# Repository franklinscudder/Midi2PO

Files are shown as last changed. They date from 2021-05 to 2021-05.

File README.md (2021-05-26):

# Midi2PO
 A device that takes MIDI clock in and outputs 1v pulses at PPQN intervals compatible with a range of devices including Korg volcas and Teenage Engineering pocket operators.

## V1
An initial design outputting a 2PPQN signal for PO/Volcas.

## V2 (LC)
An untested lower cost design using a ATTiny uController.

## V3 (Switchable)
An iteration including a second LED indicator as well as a DIP switch bank to allow a range of PPQN values to be output.
Available PPQNS: 0.25, 0.5, 1, 2, 4, 6, 12, 24.

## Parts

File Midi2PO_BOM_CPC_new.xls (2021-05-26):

Line Number | Order Code | Manufacturer Name | Manufacturer Part Number | Description | Requested Qty | Quoted Qty | Unit Price | Line Price | Availability | Lead Time
1 | SC15554 | MULTICOMP PRO | 1N4148 (DO-35) | 1N4148 (DO-35)-Small Signal Diode, Single, 100 V, 150 mA, 1 V, 4 ns, 2 A | 5 | 5 | £0.03 | £0.15 | 1761 | 1,761 in stock ready for despatch (UK stock)
2 | SC15646 | SEEED STUDIO | 102010328 | 102010328-Seeeduino XIAO Arduino Controller, SAMD21 Cortex M0+ | 1 | 1 | £5.98 | £5.98 | 63 | 63 in stock ready for despatch (UK stock)
3 | SC17276 | ON SEMICONDUCTOR | 6N138M | 6N138M-OPTOCOUPLER, DARLINGTON, 5KV, DIP-8 | 1 | 1 | £0.89 | £0.89 | 16 | 16 in stock ready for despatch (UK stock)
4 | CN21849 | MULTICOMP | SPC21344 | SPC21344-3.5mm Jack Socket, Stereo 3 Pole Switched, PCB | 1 | 1 | £0.77 | £0.77 | 61 | 61 in stock ready for despatch (UK stock)
5 | SC15414 | MULTICOMP PRO | MCL053GD | MCL053GD-LED, Green, 5mm, 2.1V | 10 | 10 | £0.05 | £0.50 | 1454 | 1,454 in stock ready for despatch (UK stock)
6 | AV19824 | PRO SIGNAL | PSG03463 | PSG03463-5 Pin PCB Mount DIN Socket with Silver Plated Contacts | 1 | 1 | £0.78 | £0.78 | 355 | 355 in stock ready for despatch (UK stock)
7 | SC16304 | TEXAS INSTRUMENTS | TL071CP | TL071CP-IC, OP AMP, JFET LOW NOISE, DIP8 | 1 | 1 | £0.43 | £0.43 | Out of Stock
8 | SW05533 | MULTICOMP PRO | MCNDA-03V | MCNDA-03V-DIP Switch, 3-Pole, SPST-NO, Slide Actuation, 24VDC, Right Angle | 1 | 1 | £0.50 | £0.50 | 11 | 11 in stock ready for despatch (UK stock)
9 | RE03791 | MULTICOMP PRO | MCF 0.25W 100R | MCF 0.25W 100R-Resistor, 0.25W 5% 100R, 100 Pack | 1 | 1 | £0.55 | £0.55 | 272 | 272 in stock ready for despatch (UK stock)
10 | RE03806 | MULTICOMP PRO | MCF 0.25W 1K8 | MCF 0.25W 1K8-Resistor, 0.25W 5% 1K8, 100 Pack | 1 | 1 | £0.55 | £0.55 | 17 | 17 in stock ready for despatch (UK stock)
11 | RE03798 | MULTICOMP PRO | MCF 0.25W 390R | MCF 0.25W 390R-Resistor, 0.25W 5% 390R, 100 Pack | 1 | 1 | £0.55 | £0.55 | 12 | 12 in stock ready for despatch (UK stock)

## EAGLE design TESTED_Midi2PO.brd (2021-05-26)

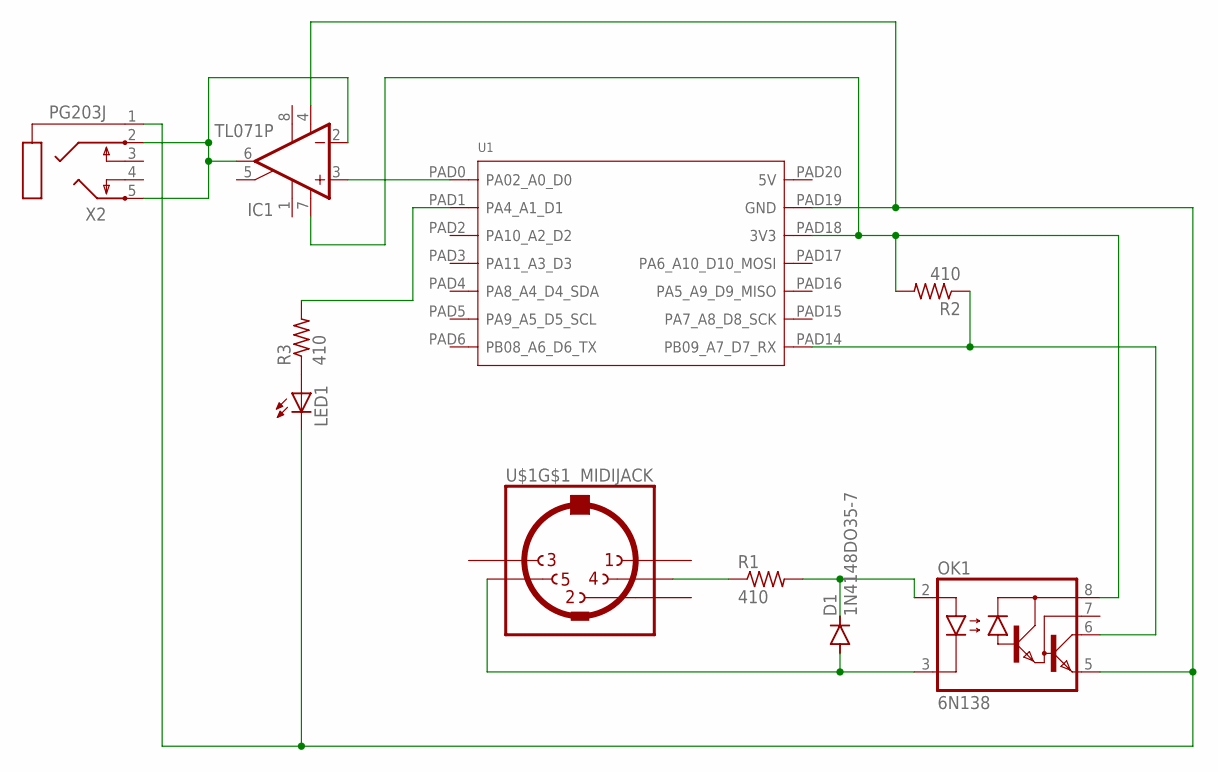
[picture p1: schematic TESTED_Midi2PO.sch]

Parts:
D1: 1N4148DO35-7; DO35-7
IC1: TL071P; DIL08
LED1: LED5MM
OK1: 6N138; DIL08
R1, R2, R3: 410; 0207/9
U1: MOUDLE-SEEEDUINO-XIAO; MOUDLE14P-2.54-21X17.8MM
U$1: MIDIJACK; CP-2350
X2: PG203J

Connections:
unnamed: D1.C, OK1.2 (A), R1.2
unnamed: R1.1, U$1.4
unnamed: D1.A, OK1.3 (C), U$1.5
unnamed 3: IC1.4 (V-), LED1.K (C), OK1.5 (GND), U1.PAD19 (GND), X2.1; also elsewhere on the board
unnamed: OK1.6 (VO), R2.1, U1.PAD14 (PB09_A7_D7_RX)
unnamed: IC1.7 (V+), OK1.8 (VCC), R2.2, U1.PAD18 (3V3)
unnamed: IC1.3 (+IN), U1.PAD0 (PA02_A0_D0)
unnamed: LED1.A, R3.1
unnamed: R3.2, U1.PAD1 (PA4_A1_D1)
unnamed 9: IC1.2 (-IN), IC1.6 (OUT), X2.2, X2.5; also elsewhere on the board

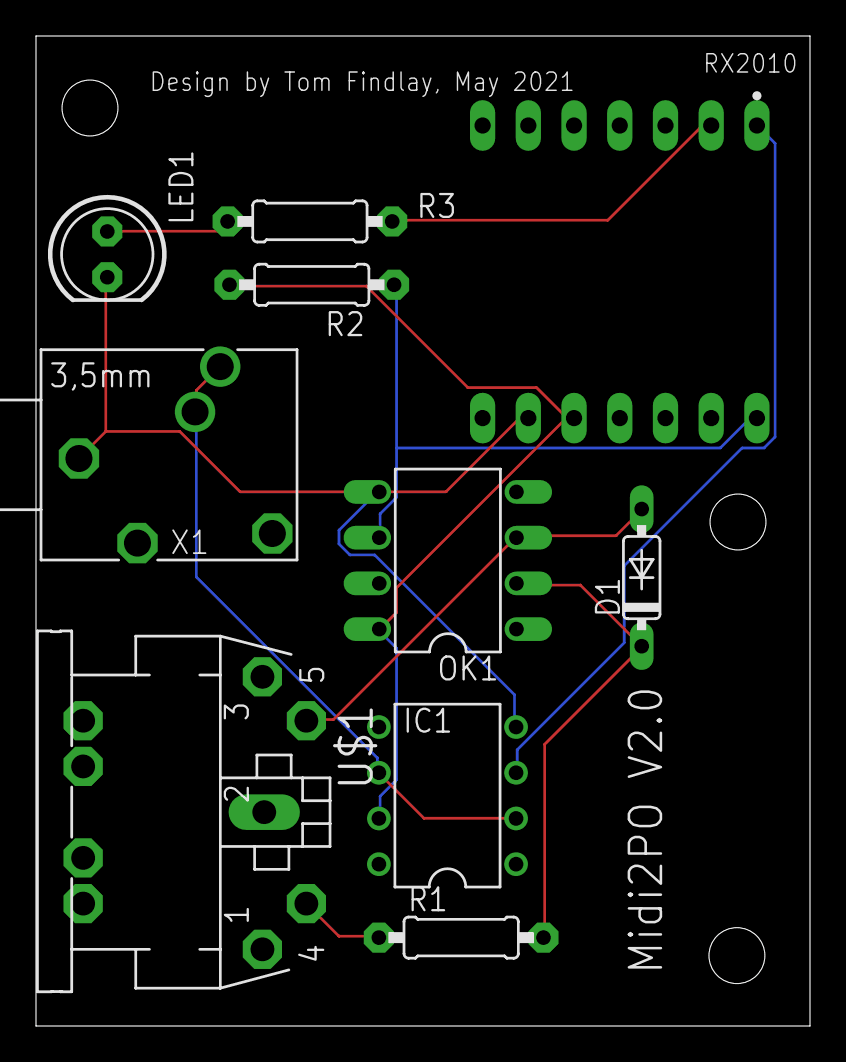
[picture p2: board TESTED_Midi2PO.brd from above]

Board: 2 copper layers, 43.0 x 55.0 mm, 10 parts (0 on the bottom side), 10 nets.

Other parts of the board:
X1: 1503_09; PG203J

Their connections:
unnamed 3: X1.1; also elsewhere on the board
unnamed 9: X1.2, X1.3; also elsewhere on the board

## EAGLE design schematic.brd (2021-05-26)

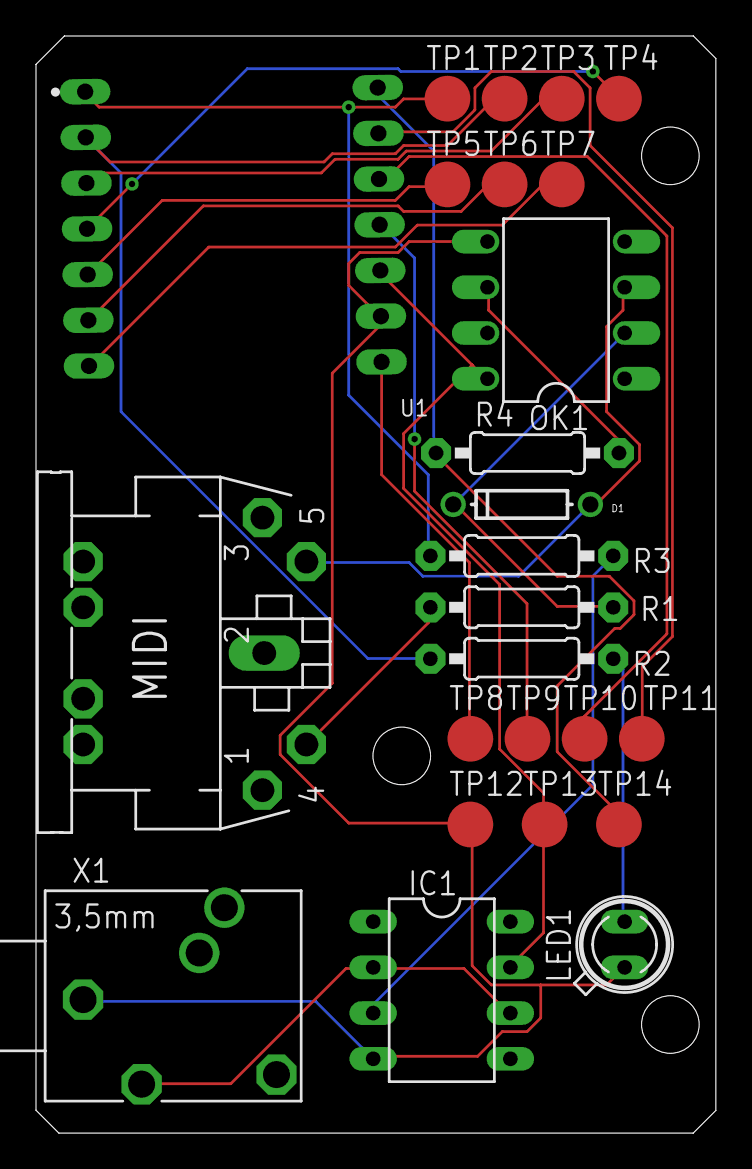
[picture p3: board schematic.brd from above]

Board: 2 copper layers, 37.8 x 60.9 mm, 25 parts (0 on the bottom side), 21 nets.

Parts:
D1: DO-1N4148
IC1: TL071P; DIL08
LED1: SFH480
MIDI: MIDIJACK; CP-2350
OK1: 6N138; DIL08
R1: 220; 0207/10
R2: 100; 0207/10
R3: 1k; 0207/10
R4: 270; 0207/10
TP1, TP2, TP3, TP4, TP5, TP6, TP7, TP8, TP9, TP10, TP11, TP12, TP13, TP14: TPB2,54; B2,54
U1: MOUDLE14P-2.54-21X17.8MM
X1: PG203J

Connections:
unnamed: D1.C, OK1.2, R1.2
unnamed: MIDI.4, R1.1
unnamed: D1.A, MIDI.5, OK1.3
unnamed: TP3.TP, U1.PAD2
unnamed: IC1.7, OK1.8, TP13.TP, U1.PAD18
unnamed: R4.1, TP14.TP, U1.PAD14
unnamed: TP4.TP, U1.PAD3
unnamed: R3.2, TP1.TP, U1.PAD0
unnamed: TP5.TP, U1.PAD4
unnamed: IC1.3, R3.1
unnamed: IC1.2, IC1.6, X1.5
unnamed: TP6.TP, U1.PAD5
unnamed: TP7.TP, U1.PAD6
unnamed: LED1.A, R2.1
unnamed: IC1.4, LED1.K, OK1.5, TP12.TP, U1.PAD19, X1.1
unnamed: R2.2, TP2.TP, U1.PAD1
unnamed: TP8.TP, U1.PAD20
unnamed: TP9.TP, U1.PAD17
unnamed: TP10.TP, U1.PAD16
unnamed: TP11.TP, U1.PAD15
unnamed: OK1.6, R4.2

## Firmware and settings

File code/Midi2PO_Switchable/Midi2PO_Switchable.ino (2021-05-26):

/*
 * Midi2PO_Switchable Firmware V1.0
 * Thomas Findlay (Findlaytel@gmail.com)
 * 26 May 2021
 */

int incomingByte = 0; // for incoming serial data
int clockCount = 0;
bool started = false;
int mode = 12;
static int modes[] = {96, 48, 24, 12, 6, 4, 2, 1}; // PPQN = 0.25 0.5 1 2 4 6 12 24

#define DACPin 0
#define sw1Pin 8
#define sw2Pin 9
#define sw3Pin 10

#define LEDPin 1
#define PwrLEDPin 2

void setup() {
  SerialUSB.begin(115200);
  Serial1.begin(31250);
  pinMode(DACPin, OUTPUT);
  pinMode(sw1Pin, INPUT_PULLUP);
  pinMode(sw2Pin, INPUT_PULLUP);
  pinMode(sw3Pin, INPUT_PULLUP);
  pinMode(LEDPin, OUTPUT);
  pinMode(PwrLEDPin, OUTPUT);
  digitalWrite(PwrLEDPin, HIGH);
  analogWriteResolution(10);
}

int switchState() {
  // query DIP switch states, return mode index
  int state = 0;
  state += !digitalRead(sw1Pin);
  state += !digitalRead(sw2Pin) * 2;
  state += !digitalRead(sw3Pin) * 4;

  return state;
}

void loop() {

  if (not started){
    mode = modes[switchState()];
    SerialUSB.println("Mode: ");
    SerialUSB.println(mode);
  }

  // send data only when you receive data:
  if (Serial1.available() > 0) {
    // read the incoming byte:
    incomingByte = Serial1.read();

    // midi clock byte
    if (incomingByte == 248) {
      SerialUSB.println("Clock!");
      clockCount++;
      SerialUSB.println(clockCount);
    }

    // midi start or continue byte
    else if (incomingByte == 250 or incomingByte == 251) {
      SerialUSB.println("Start!");
      started = true;
    }

    // midi stop byte
    else if (incomingByte == 252) {
      SerialUSB.println("Stop!");
      started = false;
    }

    digitalWrite(LEDPin, LOW);
    if (clockCount == mode and started) {
      digitalWrite(LEDPin, HIGH);
      analogWrite(DACPin, 0);
      delayMicroseconds(2500);
      analogWrite(DACPin, 1024/3.3);
    }

    clockCount = clockCount % mode; 
  }
}

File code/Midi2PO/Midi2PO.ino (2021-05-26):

int incomingByte = 0; // for incoming serial data
int clockCount = 0;
bool started = false;

#define DACPin 0

void setup() {
  SerialUSB.begin(115200); // opens serial port, sets data rate to 9600 bps
  Serial1.begin(31250);
  pinMode(0, OUTPUT);
  analogWriteResolution(10);
}

void loop() {
  // send data only when you receive data:
  if (Serial1.available() > 0) {
    // read the incoming byte:
    incomingByte = Serial1.read();

    if (incomingByte == 248) {
      SerialUSB.println("Clock!");
      clockCount++;
      SerialUSB.println(clockCount);
    }

    else if (incomingByte == 250) {
      SerialUSB.println("Start!");
      started = true;
    }

    else if (incomingByte == 252) {
      SerialUSB.println("Stop!");
      started = false;
    }

    if (clockCount == 12 and started) {
      analogWrite(DACPin, 0);
      delayMicroseconds(2500);
      analogWrite(DACPin, 1024/3.3);
    }

    clockCount = clockCount % 12;

    
  }
}
